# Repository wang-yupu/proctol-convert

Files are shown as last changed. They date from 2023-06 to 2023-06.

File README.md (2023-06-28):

# proctol-convert
usb转i2c、spi、uart、pwm、gpio、swd、adc  
基于RP2040制作  
>设计之初是为了平替85多的Debug probe  
>最低成本约80元(自己制作钢网的话)  
## PCB制造注意事项  
pcb用嘉立创eda画的，修改导入dxf而不是ad的文件  
bom表中不含rp2040和W25Q16JVUXIQ(rp2040的flash)  
推荐使用[立创商城](http://szlcsc.com "立创商城")购买，bom可全部匹配  
同时可以把pcb打了再贴片  
## 用[嘉立创](http://jlc.com "嘉立创")的制作成本  
(元器件价格约80元(不含运费))
下表中价格不含元器件，不含手工成本

| 使用的功能  | 组合0 | 组合1 |
| --- | --- | --- |
| SMT贴片(2件,全贴) | 是 | 否 |
| 开激光钢网 | 否 | 是 |
| 价格(RMB) | 400(含元器件) | 100 |

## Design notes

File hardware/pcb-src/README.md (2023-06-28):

PCB的源文件  
使用嘉立创eda制作 另附altium designer文件  
(我和嘉立创eda不负责转到altium designer的差异)

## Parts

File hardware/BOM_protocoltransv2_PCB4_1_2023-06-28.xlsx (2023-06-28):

No. | Quantity | Comment | Designator | Footprint | Value | Primary Category | Secondary Category | Manufacturer Part | Manufacturer | Supplier Part | Supplier | LCSC Price | LCSC Stock | Unique ID | Device | Name
1 | 2 | 2.54-1*4P母 | ADC#,SPI0 | HDR-TH_4P-P2.54-V-F |  | 连接器 | 排母 | 2.54-1*4P母 | BOOMELE(博穆精密) | C2718488 | LCSC | 0.2652 |  | gge45,gge64 | 2.54-1*4P母 | 2.54-1*4P母
2 | 1 | SKRPACE010 | BOOTSEL | KEY-SMD_4P-L4.2-W3.2-P2.20-LS4.6 |  | 按键/开关 | 轻触开关 | SKRPACE010 | ALPSALPINE(阿尔卑斯阿尔派) | C139797 | LCSC | 0.280975 |  | gge43 | SKRPACE010 | SKRPACE010
3 | 1 | 2.2uF | C2 | C0402 | 2.2uF | 电容 | 贴片电容(MLCC) | CL05A225MQ5NSNC | SAMSUNG(三星) | C12530 | LCSC | 0.016409 |  | gge16 | CL05A225MQ5NSNC | 2.2uF
4 | 2 | 15pF | C3,C4 | C0201 | 15pF | 电容 | 贴片电容(MLCC) | CL03C150JA3ANNC | SAMSUNG(三星) | C575454 | LCSC | 0.035225 |  | gge1,gge2 | CL03C150JA3ANNC | 15pF
5 | 2 | 47uF | C6,C8 | C0805 | 47uF | 电容 | 贴片电容(MLCC) | GRM21BR60J476ME01L | muRata(村田) | C385043 | LCSC | 0.70128 |  | gge11,gge15 | GRM21BR60J476ME01L | 47uF
6 | 13 | 100nF | C7,C9,C10,C11,C12,C13,C14,C15,C16,C17,C18,C19,C21 | C0201 | 100nF | 电容 | 贴片电容(MLCC) | GRM033R60J104KE19D | muRata(村田) | C76928 | LCSC | 0.008271 |  | gge17,gge19,gge20,gge21,gge22,gge23,gge24,gge25,gge26,gge27,gge28,gge29,gge47 | GRM033R60J104KE19D | 100nF
7 | 1 | 1nF | C20 | C0201 | 1nF | 电容 | 贴片电容(MLCC) | GRM033R71E102KA01D | muRata(村田) | C76943 | LCSC | 0.009848 |  | gge33 | GRM033R71E102KA01D | 1nF
8 | 1 | MBR120VLSFT1G | D1 | SOD-123F_L2.8-W1.8-LS3.7-RD |  | 二极管 | 肖特基二极管 | MBR120VLSFT1G | onsemi(安森美) | C223608 | LCSC | 0.845366 |  | gge10 | MBR120VLSFT1G | MBR120VLSFT1G
9 | 1 | 2.2uH | D2 | IND-SMD_L2.5-W2.0 | 2.2uH | 电感/线圈/变压器 | 功率电感 | SRN2512-2R2M | BOURNS | C2041574 | LCSC | 1.7257 |  | gge14 | SRN2512-2R2M | 2.2uH
10 | 1 | NCD0603R1 | ERR | LED0603-RD_RED |  | 光耦/LED/数码管/光电器件 | 发光二极管/LED | NCD0603R1 | 国星光电 | C84263 | LCSC | 0.051942 |  | gge54 | NCD0603R1_C84263 | NCD0603R1
11 | 4 | SZYY0603Y | IOMON0,IOMON1,IOMON2,IOMON3 | LED0603-R-RD_YELLOW |  | 光耦/LED/数码管/光电器件 | 发光二极管/LED | SZYY0603Y | yongyu(永裕光电) | C434424 | LCSC | 0.076857 |  | gge56,gge57,gge58,gge59 | SZYY0603Y | SZYY0603Y
12 | 5 | SM03B-SRSS-TB(LF)(SN) | I²C0,I²C1,SWD,UART0,UART1 | CONN-SMD_SM03B-SRSS-TB-LF-SN-P |  | 连接器 | 线对板/线对线连接器 | SM03B-SRSS-TB(LF)(SN) | JST | C160403 | LCSC | 0.8607 |  | gge36,gge37,gge38,gge39,gge42 | SM03B-SRSS-TB(LF)(SN) | SM03B-SRSS-TB(LF)(SN)
13 | 2 | DS1023-2*3SF11 | I²C#,UART# | HDR-TH_6P-P2.54-V-F-R2-C3-S2.54 |  | 连接器 | 排母 | DS1023-2*3SF11 | CONNFLY | C92272 | LCSC | 0.54267 |  | gge40,gge41 | DS1023-2*3SF11 | DS1023-2*3SF11
14 | 2 | 2.54-1*3P母 | PWM#,SWD | HDR-TH_3P-P2.54-V-F |  | 连接器 | 排母 | 2.54-1*3P母 | BOOMELE(博穆精密) | C146243 | LCSC | 0.3536 |  | gge53,gge67 | 2.54-1*3P母 | 2.54-1*3P母
15 | 2 | 1kΩ | R1,R2 | R0402 | 1kΩ | 电阻 | 贴片电阻 | AECR0402F1K00K9 | RESI(开步睿思） | C328304 | LCSC | 0.024854 |  | gge3,gge4 | AECR0402F1K00K9 | 1kΩ
16 | 1 | 5.6kΩ | R3 | R0402 | 5.6kΩ | 电阻 | 贴片电阻 | CR0402F5K60Q10Z | EVER OHMS(天二科技) | C881140 | LCSC | 0.003581 |  | gge8 | CR0402F5K60Q10Z | 5.6kΩ
17 | 1 | 10kΩ | R4 | R0603 | 10kΩ | 电阻 | 贴片电阻 | 0603WAF1002T5E | UNI-ROYAL(厚声) | C25804 | LCSC | 0.005512 |  | gge9 | 0603WAF1002T5E | 10kΩ
18 | 3 | 100kΩ | R5,R6,R13 | R0402 | 100kΩ | 电阻 | 贴片电阻 | RC0402FR-07100KL | YAGEO(国巨) | C60491 | LCSC | 0.003259 |  | gge12,gge13,gge34 | RC0402FR-07100KL | 100kΩ
19 | 1 | 1Ω | R11 | R0402 | 1Ω | 电阻 | 贴片电阻 | RC0402FR-071RL | YAGEO(国巨) | C185446 | LCSC | 0.009514 |  | gge30 | RC0402FR-071RL | 1Ω
20 | 1 | 200Ω | R12 | R0603 | 200Ω | 电阻 | 贴片电阻 | RC0603FR-07200RL | YAGEO(国巨) | C114664 | LCSC | 0.007603 |  | gge31 | RC0603FR-07200RL | 200Ω
21 | 1 | 200kΩ | R14 | R0402 | 200kΩ | 电阻 | 贴片电阻 | RC0402FR-07200KL | YAGEO(国巨) | C114763 | LCSC | 0.003941 |  | gge35 | RC0402FR-07200KL | 200kΩ
22 | 6 | 470Ω | R15,R19,R20,R21,R22,R23 | R0402 | 470Ω | 电阻 | 贴片电阻 | RC0402FR-07470RL | YAGEO(国巨) | C114877 | LCSC | 0.00382 |  | gge52,gge55,gge60,gge61,gge62,gge63 | RC0402FR-07470RL | 470Ω
23 | 3 | 100Ω | R16,R17,R18 | R0402 | 100Ω | 电阻 | 贴片电阻 | CR0402F100RQ10Z | EVER OHMS(天二科技) | C881021 | LCSC | 0.003582 |  | gge48,gge49,gge50 | CR0402F100RQ10Z | 100Ω
24 | 1 | 27Ω | R25 | R0201 | 27Ω | 电阻 | 贴片电阻 | RC0201FR-0727RL | YAGEO(国巨) | C273268 | LCSC | 0.005312 |  | gge65,gge66 | RC0201FR-0727RL | 27Ω
25 | 1 | 19-217/GHC-YR1S2/3T | SYS | LED0603-RD |  | 光耦/LED/数码管/光电器件 | 发光二极管/LED | 19-217/GHC-YR1S2/3T | EVERLIGHT(亿光) | C72043 | LCSC | 0.167861 |  | gge51 | 19-217/GHC-YR1S2/3T | 19-217/GHC-YR1S2/3T
26 | 1 | RT6150BGQW | U5 | WSON-10_L2.5-W2.5-P0.50-BL-EP |  | 电源芯片 | DC-DC电源芯片 | RT6150BGQW | RICHTEK(立锜) | C147972 | LCSC | 11.18 |  | gge7 | RT6150BGQW | RT6150BGQW
27 | 1 | DMG1012T-13 | U6 | SOT-523-3_L1.6-W0.8-P1.00-LS1.6-BR |  | 三极管/MOS管/晶体管 | 场效应管(MOSFET) | DMG1012T-13 | DIODES(美台) | C3280264 | LCSC | 0.411272 |  | gge32 | DMG1012T-13 | DMG1012T-13
28 | 1 | 74AUP1T17GWH | U14 | TSSOP-5_L2.1-W1.3-P0.65-LS2.2-BR |  | 逻辑器件 | 缓冲器/驱动器/收发器 | 74AUP1T17GWH | Nexperia(安世) | C545951 | LCSC | 8.09 |  | gge46 | 74AUP1T17GWH | 74AUP1T17GWH
29 | 1 | MicroXNJ | USB1 | MICRO-USB-SMD_MICROXNJ |  | 连接器 | USB连接器 | MicroXNJ | SHOU HAN(首韩) | C404969 | LCSC | 0.212177 |  | gge44 | MicroXNJ | MicroXNJ
30 | 1 | 12MHz | X1 | CRYSTAL-SMD_4P-L3.2-W2.5-BL | 12MHz | 晶振/振荡器/谐振器 | 无源晶振 | X322512MMB4SI | YXC(扬兴晶振) | C50430 | LCSC | 0.47181 |  | gge18 | X322512MMB4SI | 12MHz

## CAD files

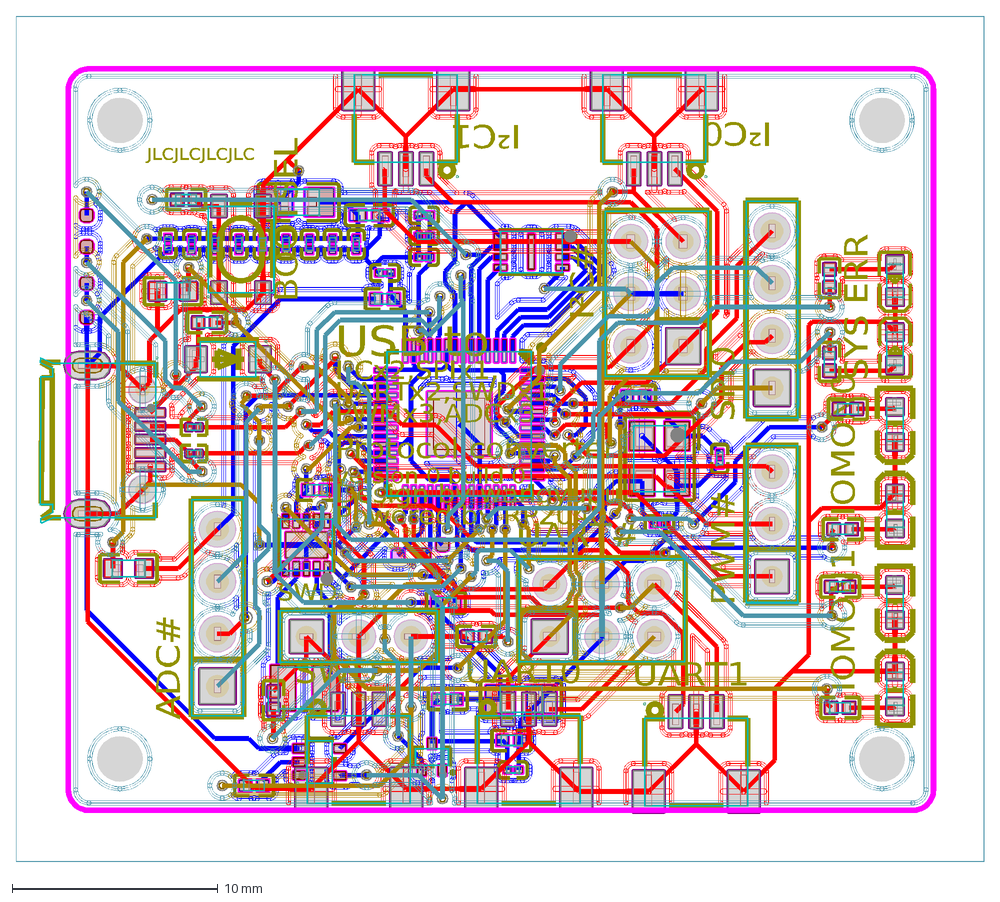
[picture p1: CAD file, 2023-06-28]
hardware/pcb-src/dxf-pcb-v0b0.dxf
USB to
I²Cx2,SPIx1,
UARTx2,SWDx1,
PWMx3,ADCx3
Protocol converter
version 0 build 0
UART0
UART1
I²C0
I²C1
UART#
SWD
BOOTSEL
SPI0
SYS
PWM#
ERR
IOMON0
IOMON1
ADC#
Design by wangyupu
Powered by RP2040
I²C#
JLCJLCJLCJLC

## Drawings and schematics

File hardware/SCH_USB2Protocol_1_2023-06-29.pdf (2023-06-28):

# QSPI_SD3 51 DVDD ⁵⁰

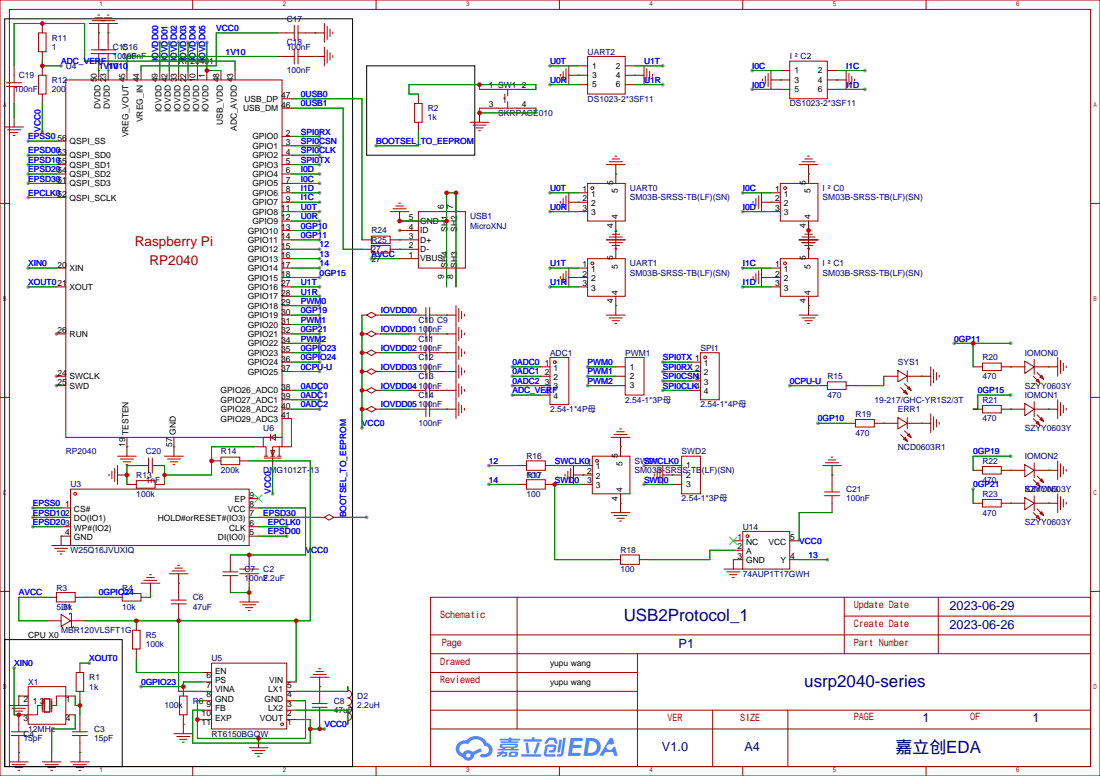
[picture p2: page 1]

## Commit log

2023-06-28 更新README.md
2023-06-28 hardware部分
2023-06-28 修改hardware部分中的pcb的readme
2023-06-28 上传ad、dxf、gerber
    [dxf-pcb-v0b0.dxf]
2023-06-28 bom表(不含rp2040和flash)
    [BOM_protocoltransv2_PCB4_1_2023-06-28.xlsx]
2023-06-28 修改README.me
2023-06-28 修改readme.md
